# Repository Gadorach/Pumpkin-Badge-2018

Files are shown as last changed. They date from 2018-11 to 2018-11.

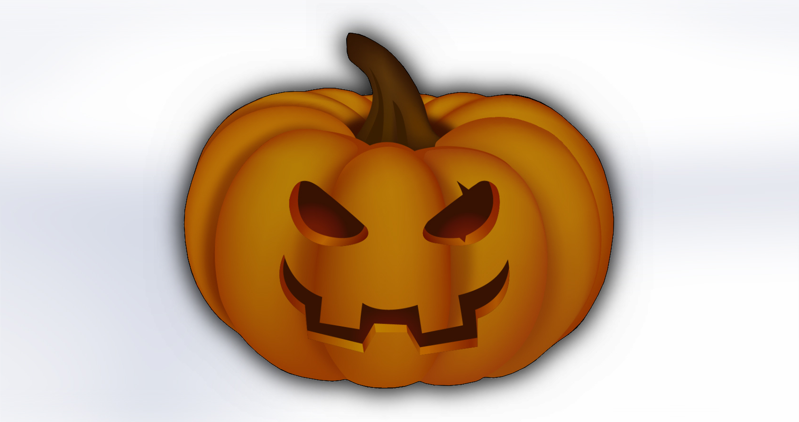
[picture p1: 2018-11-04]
3D/Pumpkin_Board_Layout.JPG

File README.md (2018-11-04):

# Pumpkin Badge 2018
A simple Halloween-themed LED badge for fun.
Runs on a PIC 12F1572, my 8-pin micro of choice.
Contains my adapted and working I2C library, based on code by Saeed.

Saeed's Blog Here: http://saeedsolutions.blogspot.com/2012/11/pic12f675-i2c-bit-banging-code-proteus.html

Also stole and adapted code for driving the PCA9685 LED Driver used in this project from TeraHz.

TeraHz Git Here: https://github.com/TeraHz/PCA9685

I would've made everything myself, but time was certainly not available for extensive messing about with code. Even with the adaptions, it took a logic analyzer and my Rigol to track down issues with the I2C library and fix my PCA9685 driver code.

Here's a link to my project page on MBChip, along with a simplified parts list.

MBChip Community: https://www.pcbway.com/project/shareproject/Pumpkin_Badge_V1.html

I plan to do more of these little fun boards in the future based on this chipset, so look forward to Christmas and Valentines boards next.

Note, a few glaring flaws exist on the V1 board that I intend to fix later, mainly that you can't both have the PCA9685 installed AND use the ICSP port simultaneously. That's my bad, and already have a fix, but need to finish reworking the board in a few other ways as well to make it a worthy V2. Just program the 12F1572 either before installing the PCA9685, or program the 12F1572 out of system before installing it.

Currently there's only 4 LED patterns, but it's fully programmable, so feel free to make your own!

Anyway, Enjoy!

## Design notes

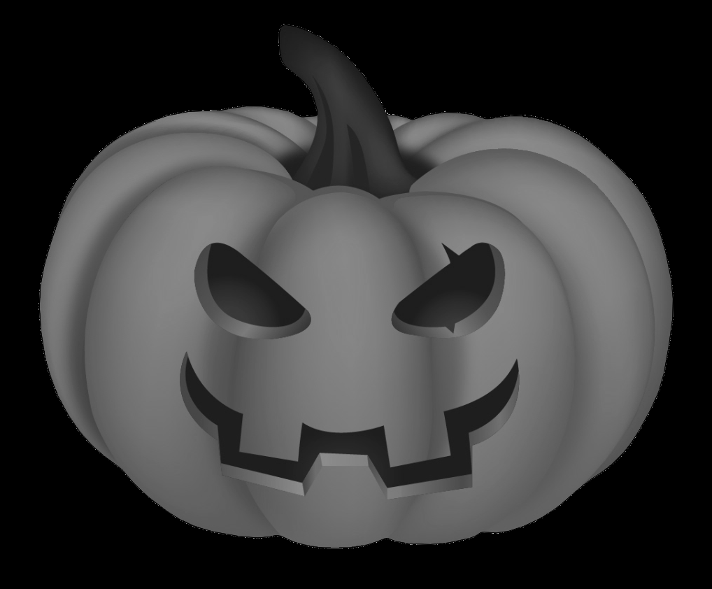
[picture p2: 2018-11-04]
3D/Pumpkin_Board_Layout.bmp

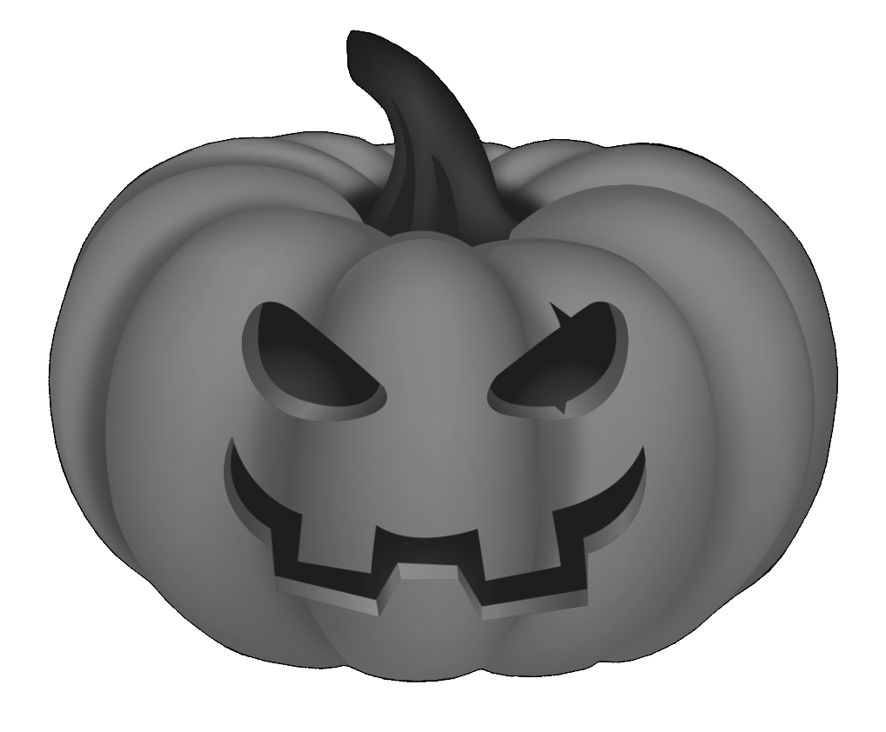
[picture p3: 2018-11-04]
3D/Pumpkin_Board_Layout_WHT.bmp

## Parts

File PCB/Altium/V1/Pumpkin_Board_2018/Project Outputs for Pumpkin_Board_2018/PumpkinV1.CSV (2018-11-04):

Bill of Material for
On 2018-10-17 at 12:50:49 AM
Comment | Pattern | Quantity | Components
430156043726 | 4301x60437x6 | 1 | BTN | WS-TATV 6x6 mm THT
BC3AAAPC | BC3AAAPC | 1 | * | AAA Battery Holder, 3 Cell
Cap2 | CAPR5-4X5 | 1 | C1 | Capacitor
Diode 1N4148 | DO-35 | 1 | D1 | High Conductance Fast Diode
Header 6H | HDR1X6H | 1 | ICSP | Header, 6-Pin, Right Angle
LED | 1608[0603] | 17 | LED0, LED1, LED2, LED3, LED4, LED5, LED6, LED7, LED8, LED9, LED10, LED11, LED12, LED13, LED14, LED15, PLED | Typical RED, GREEN, YELLOW, AMBER GaAs LED
PCA9685PW | TSSOP28 | 1 | U2 | IC LED DRIVER RGBA 28-TSSOP
PIC12LF1572-E/P | MCHP-PDIP-P8 | 1 | U1 | Microcontroller with High Precision 16-Bit PWMs, 2K (x14-Bit words) Program Memory, 256 Bytes SRAM, 6 I/O, Extended Temperature, 8-Pin PDIP (P8), Tube
PIC12LF1572-I/SN | MCHP-SOIC-SN8_N | 1 | U1x | Microcontroller with High Precision 16-Bit PWMs, 2K (x14-Bit words) Program Memory, 256 Bytes SRAM, 6 I/O, Industrial Temperature, 8-Pin SOIC (SN8), Tube
Res Pack3 | EXB2HV | 2 | RA1, RA2 | Isolated Resistor Network
Res3 | 2012[0805] | 5 | R1, R2, R3, R_OE, R_PLED | Resistor

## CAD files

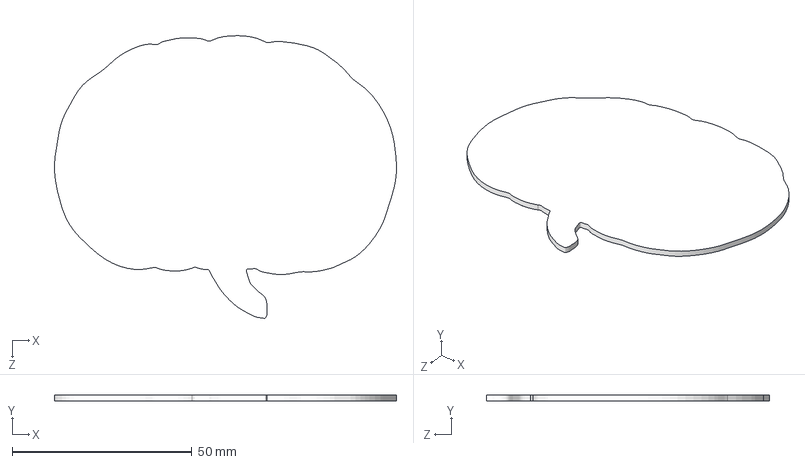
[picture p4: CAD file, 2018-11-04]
3D/Pumpkin_Board_Layout.STEP
95.1 x 1.60 x 78.6 mm

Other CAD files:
Code/V1/12F1572_Pumpkin_Badge.X/dist/default/production/12F1572_Pumpkin_Badge.X_-_ORIG.production.obj
3D/Pumpkin_Board_Layout.SLDPRT

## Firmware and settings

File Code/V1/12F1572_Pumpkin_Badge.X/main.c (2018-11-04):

//PIC 12F1572 Pumpkin Badge (MPLABX)
//By Wesley Savoie
//Pin 1 = +4V
//Pin 8 = 0V (GND)
//Refer to schematic for the rest!

// CONFIG1
#pragma config FOSC = INTOSC    // (INTOSC oscillator; I/O function on CLKIN pin)
#pragma config WDTE = OFF       // Watchdog Timer Enable (WDT disabled)
#pragma config PWRTE = OFF      // Power-up Timer Enable (PWRT disabled)
#pragma config MCLRE = OFF      // MCLR Pin Function Select (MCLR/VPP pin function IO)
#pragma config CP = OFF         // Flash Program Memory Code Protection (Program memory code protection is disabled)
#pragma config BOREN = OFF      // Brown-out Reset Enable (Brown-out Reset disabled)
#pragma config CLKOUTEN = OFF   // Clock Out Enable (CLKOUT function is disabled. I/O or oscillator function on the CLKOUT pin)

// CONFIG2
#pragma config WRT = OFF        // Flash Memory Self-Write Protection (Write protection off)
#pragma config PLLEN = ON       // PLL Enable (4x PLL enabled)
#pragma config STVREN = ON      // Stack Overflow/Underflow Reset Enable (Stack Overflow or Underflow will cause a Reset)
#pragma config BORV = LO        // Brown-out Reset Voltage Selection (Brown-out Reset Voltage (Vbor), low trip point selected.)
#pragma config LPBOREN = OFF    // Low Power Brown-out Reset enable bit (LPBOR is disabled)
#pragma config LVP = ON         // Low-Voltage Programming Enable (Low-voltage programming enabled)

// INCLUDES
#include "Includes.h"

// DEFINITIONS
#define PLED LATAbits.LATA5 //define PLED latch setting for readability
#define BTN_INP TRISAbits.TRISA2
#define BTN PORTAbits.RA2

// Global Variables
unsigned char LEDMODE = 0; //Holds default mode data
unsigned char BTN_DETECT = 0; //Holds default button trigger detection data
unsigned char PWM_FADE_HOLD = 0;

unsigned char PATTERN_HOLD_1 = 0;
unsigned char PATTERN_HOLD_2 = 0;
unsigned char PATTERN_HOLD_SW = 0;

void InitCCT(void){
    //configure main registers
    OSCCON  = 0x7A;             //Setup internal osc to 16MHz
    OSCSTAT = 0x00;             //disable unnecessary modules
    OSCTUNE = 0x00;             //set INTOSC to factory calibrated settings
        
    //setup ports
    ANSELA = 0b00000000; // all pins to digital
    LATA   = 0b00000000; // all latch bits low
    TRISA  = 0b00001100; // all pins to outputs except RA2(BTN) & RA3 (MCLR)
    //WPUA   = 0b00001000; // enable weak pull-ups on RA3
}

void InitPWM(void){
    //Alt PWM1 (PIN 2 (RA5))
    APFCONbits.P1SEL = 1; //Set RA5 as PWM1 Output
    PWM1CLKCON = 0b00110001; // HFINTOSC clock, 1:8 prescaler
    PWM1PH = 0; // phase
    PWM1DC = 0; // duty cycle
    PWM1PR = 4000; // period
    PWM1CON = 0b11000000; // module enable, output enable, normal polarity, standard mode
}

unsigned int PLED_setDC(unsigned int setDC){
    if(setDC > 100){
        setDC = 4095;
    } else {
        setDC = ((setDC*4095)/100);
    }
    PWM1DC = 4095 - setDC;  //Set PWM Duty Cycle (100% = 0, 0% = 4095, so 4096 steps) (Remember, it's inverted as the LED is being pulled to GND to turn on)
    PWM1LD = 1;     //Update the PWM state
}

void initLEDArray(void){
    PCA9685_reset();          //Reset the PCA9685 to prepare it for new data
    PCA9685_setPWMFreq(1000); //Set PWM Frequency to 1000Hz
    PCA9685_setAllOff();
}

void main(void){    
    InitCCT();	// Turn off ADC and comparator to make pins digital IOs
    InitI2C();	// Initialize i2c pins
    
    InitPWM();      //Initialize RA5 PWM
    PLED_setDC(50); //Initialize and set the Power LED PWM Duty Cycle (0% to 100%)
    
    initLEDArray();
    
    while(1){   //Start main loop
        if(BTN == 0){
            PLED_setDC(0);
            __delay_ms(10); //debounce
            if(BTN == 0){
                while(BTN == 0); //wait until button is released
                __delay_ms(10); //debounce
                PLED_setDC(50);
                if(LEDMODE == 0){
                        LEDMODE = 1;
                } else if(LEDMODE == 1){
                        LEDMODE = 2;
                } else if(LEDMODE == 2){
                        LEDMODE = 3;
                } else if(LEDMODE == 3){
                        LEDMODE = 4;
                } else if(LEDMODE == 4){
                        LEDMODE = 0;
                }
            }
            BTN_DETECT = 1;
        }
        
        if(BTN_DETECT == 1){
            if(LEDMODE == 0){ //MODE 0 = All Off (Basic Startup Mode)
                PCA9685_setAllOff();
                PLED_setDC(80);
                __delay_ms(10);
                PLED_setDC(0);
                __delay_ms(10);
            }
            if(LEDMODE == 1){ //MODE 1 = All On (50%) (Power Save Mode)
                PCA9685_setAll(2047);
                    for(int i = 0; i < 2; i++){
                        PLED_setDC(80);
                        __delay_ms(10);
                        PLED_setDC(0);
                        __delay_ms(10);
                }
            }
            if(LEDMODE == 2){ //MODE 2 = All On (90%) (High Brightness Mode)
                PCA9685_setAll(3685);
                    for(int i = 0; i < 3; i++){
                        PLED_setDC(80);
                        __delay_ms(10);
                        PLED_setDC(0);
                        __delay_ms(10);
                }
            }
            if(LEDMODE == 3){
                for(int i = 0; i < 4; i++){
                    PLED_setDC(80);
                    __delay_ms(10);
                    PLED_setDC(0);
                    __delay_ms(10);
                }
                PWM_FADE_HOLD = 1;
            }
            if(LEDMODE == 4){
                for(int i = 0; i < 5; i++){
                    PLED_setDC(80);
                    __delay_ms(10);
                    PLED_setDC(0);
                    __delay_ms(10);
                }
                PCA9685_setAllOff();
            }
            BTN_DETECT = 0;
        }
        
        if(LEDMODE == 3){ //MODE 3 = Quick Cycle Mode
            if(PWM_FADE_HOLD == 0){
                for(int i = 0; i < 4096; i+=128){
                    if(BTN == 0) break;
                    PCA9685_setAll(i);
                    __delay_ms(10);
                }
            }
            if(PWM_FADE_HOLD == 1){
                for(int i = 4096; i > 0; i-=128){
                    if(BTN == 0) break;
                    PCA9685_setAll(i);
                    __delay_ms(10);
                }
            }
            if(PWM_FADE_HOLD == 0) {PWM_FADE_HOLD = 1;} else {PWM_FADE_HOLD = 0;};
        }
        
        if(LEDMODE == 4){ //MODE 3 = Quick Cycle Mode
            PCA9685_setPWM_Simple(EYE_CYCLE_1[PATTERN_HOLD_1], 3685);
            PCA9685_setPWM_Simple(MOUTH_CYCLE_1[PATTERN_HOLD_2], 3685);
            for(unsigned char i = 0; i < 10; i++){
                __delay_ms(10);
                if(BTN == 0) break;
            }
            PCA9685_setPWM_Simple(EYE_CYCLE_1[PATTERN_HOLD_1], 1);
            PCA9685_setPWM_Simple(MOUTH_CYCLE_1[PATTERN_HOLD_2], 1);
            
            PATTERN_HOLD_1++;
            if (PATTERN_HOLD_SW == 0){
                PATTERN_HOLD_2++;
            } else {
                PATTERN_HOLD_2--;
            }
            
            if(PATTERN_HOLD_1 == 8){
                PATTERN_HOLD_1 = 0;
            }
            if(PATTERN_HOLD_2 == 10 && PATTERN_HOLD_SW == 0){
                PATTERN_HOLD_2 = 8;
                PATTERN_HOLD_SW = 1;
            } else if(PATTERN_HOLD_2 == 0 && PATTERN_HOLD_SW == 1){
                PATTERN_HOLD_SW = 0;
            }
        }
    }
}

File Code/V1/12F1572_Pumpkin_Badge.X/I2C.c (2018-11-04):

// Function Purpose: Set initial values of SCK and SDA pins
#include "Includes.h"

void InitI2C(void)
{	
	DataPinADCMask  = 1;	// Make Digital output
	ClockPinADCMask = 1;	// Make Digital output

	// Make SDA and SCK pins input initially
	SDA_DIR = 1;
	SCK_DIR = 1;
	
	// Write zero in output register of SDA and SCK pin
	SDA = 0;
	SCK = 0;
}


// Function Purpose: I2C_Start sends start bit sequence
void I2C_Start(void)
{
	Set_SCK_High;				// Make SCK pin high
	Set_SDA_High;				// Make SDA pin High
	__delay_us(HalfBitDelay);	// Half bit delay
	Set_SDA_Low;				// Make SDA Low
	__delay_us(HalfBitDelay);	// Half bit delay
}


// Function Purpose: I2C_ReStart sends start bit sequence
void I2C_ReStart(void)
{
	Set_SCK_Low;				// Make SCK pin low

	__delay_us(HalfBitDelay/2);	// Data pin should change it's value,
								// when it is confirm that SCK is low
	Set_SDA_High;				// Make SDA pin High
	
	__delay_us(HalfBitDelay/2);	// 1/4 bit delay
	Set_SCK_High;				// Make SCK pin high
	__delay_us(HalfBitDelay/2);	// 1/4 bit delay
	Set_SDA_Low;				// Make SDA Low
	__delay_us(HalfBitDelay/2);	// 1/4 bit delay
}


//Function : I2C_Stop sends stop bit sequence
void I2C_Stop(void)
{
	Set_SCK_Low;				// Make SCK pin low

	__delay_us(HalfBitDelay/2);	// Data pin should change it's value,
								// when it is confirm that SCK is low
	Set_SDA_Low;				// Make SDA pin low
	
	__delay_us(HalfBitDelay/2);	// 1/4 bit delay
	Set_SCK_High;				// Make SCK pin high
	__delay_us(HalfBitDelay/2);	// 1/4 bit delay
	Set_SDA_High;				// Make SDA high
	__delay_us(HalfBitDelay/2);	// 1/4 bit delay
}



//Function : I2C_Send_ACK sends ACK bit sequence
void I2C_Send_ACK(void)
{
	Set_SCK_Low;				// Make SCK pin low
	__delay_us(HalfBitDelay/2);	// Data pin should change it's value,
								// when it is confirm that SCK is low
	Set_SDA_Low;				// Make SDA Low
	__delay_us(HalfBitDelay/2);	// 1/4 bit delay
	Set_SCK_High;				// Make SCK pin high
	__delay_us(HalfBitDelay);	// Half bit delay
}


//Function : I2C_Send_NACK sends NACK bit sequence
void I2C_Send_NACK(void)
{
	Set_SCK_Low;				// Make SCK pin low
	__delay_us(HalfBitDelay/2);	// Data pin should change it's value,
								// when it is confirm that SCK is low
	Set_SDA_High;				// Make SDA high
	__delay_us(HalfBitDelay/2);	// 1/4 bit delay
	Set_SCK_High;				// Make SCK pin high
	__delay_us(HalfBitDelay);	// Half bit delay
}


// Function Purpose: I2C_Write_Byte transfers one byte
bit I2C_Write_Byte(unsigned char Byte)
{
	static bit ACK = 0;

	unsigned char i;		// Variable to be used in for loop
	
	for(i=0;i<8;i++)		// Repeat for every bit
	{
		Set_SCK_Low;		// Make SCK pin low
		
		__delay_us(HalfBitDelay/2);	// Data pin should change it's value,
									// when it is confirm that SCK is low

		if((Byte<<i)&0x80)  // Place data bit value on SDA pin
			Set_SDA_High;	// If bit is high, make SDA high
		else				// Data is transferred MSB first
			Set_SDA_Low;	// If bit is low, make SDA low

		__delay_us(HalfBitDelay/2);	// Toggle SCK pin
		Set_SCK_High;				// So that slave can
		__delay_us(HalfBitDelay);	// latch data bit
    }
		
	// Get ACK from slave
	Set_SCK_Low;
    Set_SDA_High;
    __delay_us(HalfBitDelay);
    Set_SCK_High;
    __delay_us(HalfBitDelay);

	DataPinADCMask = 0;		// Make digital input
	ACK = SDA_IN;           // Read data pin status
	DataPinADCMask = 1;		// Make analog output

	return ACK;
}


// Function Purpose: I2C_Read_Byte reads one byte
unsigned char I2C_Read_Byte(void)
{
	unsigned char i, RxData = 0;

	for(i=0;i<8;i++)
	{
		Set_SCK_Low;					// Make SCK pin low
		Set_SDA_High;					// Don't drive SDA 
		__delay_us(HalfBitDelay);		// Half bit delay
		Set_SCK_High;					// Make SCK pin high
		__delay_us(HalfBitDelay/2);		// 1/4 bit delay
		DataPinADCMask = 0;				// Make digital input
		RxData = RxData|(SDA_IN<<(7-i));// Captured received bit
		DataPinADCMask = 1;				// Make digital output
		__delay_us(HalfBitDelay/2);		// 1/4 bit delay
	}
 
    return RxData;						// Return received byte
}
